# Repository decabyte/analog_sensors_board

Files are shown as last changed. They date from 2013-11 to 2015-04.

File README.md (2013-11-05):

Analog Sensors Shield
=====================

__Analog Sensors Shield__ is an Arduino Leonardo shield used to interface a robotic platform with analog sensors for internal environmental monitoring and platform managment.

The shild is using most of the analog inputs available on the Leonardo, reading data from 4 temperature sensors (LM35), 4 voltage divider for battery monitoring and a small humidity sensor (HIH-4030). 

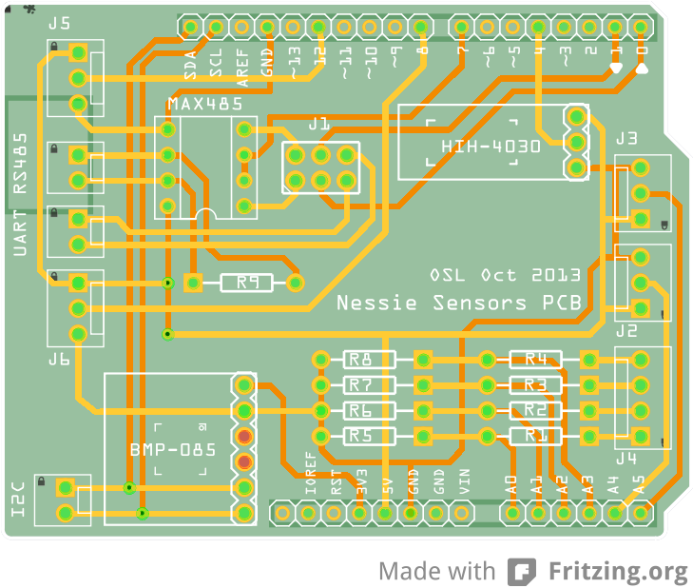
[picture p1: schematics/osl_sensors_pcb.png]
layout_pcb


In addition to the analog sensors the shield is using a BMP085 barometric pressure sensor interfaced with the I2C bus to provide extra temperature reading and platform monitoring. The BMP085 is powered by the Arduino itself using the 3.3V pin. To further expand the shield capabilities a MAX485 is included to provide an optional RS485 interface (using the J1 header one can select between UART or RS485 connectivity). The serial interfacing is achived using the Arduino hardware serial (pin 0 and 1) while the communication with the host is achieved using the 32U4 USB connection (using the CDC virtual serial profile as supported by Arduino Leonardo).

### Components

* 4 x LM35 analog temp sensor
* 4 x 24kOhm resistors (1%)
* 4 x 2.2kOhm resistors (1%)
* 1 x 150Ohm resistor (1%)
* 1 x BMP085 Breakout
* 1 x HIH-4030 Breakout

For a more detailed list look at [the bill of materials](extra/osl_sensors_bom.md) (or [html version](extra/osl_sensors_bom.html)) in the [extra](extra) subdir.

### Software

An example client python script is included in the [scripts](scripts) subdir, demostrating the use of the shield over the virtual serial connection (handling reconnects and catching exceptions). Being a an USB virtual serial connection means that the virtual interface is managed (using latest Linux distro) by `udev` subsystem and it will be attatched to the first available `/dev/ttyACMx` character device. To avoid this and to have a working symlink across reconnections customize the [rules](extra/99-local.rules) file with your Arduino's VID and PID.

Keep in mind that some extra features are missing but feel free to add or suggest them. Just clone or fork the git repository if you want to kickstart a new project.

## References

* [Temperature Sensor Tutorial](http://learn.adafruit.com/tmp36-temperature-sensor) 
* [HIH-4030 Humidity Sensor](https://www.sparkfun.com/products/9569)
* [HIH-4030 Tutorial](http://bildr.org/2012/11/hih4030-arduino/)
* [HIH-4030 Interpolation](http://forum.arduino.cc/index.php/topic,19961.0.html)
* [BMP085 Barometric Pressure Sensor](https://www.sparkfun.com/products/11282)
* [BMP085 Tutorial](https://www.sparkfun.com/tutorials/253)

## LICENSE - "MIT License"

Copyright (c) 2013-2014 Valerio De Carolis, http://decabyte.it

Permission is hereby granted, free of charge, to any person
obtaining a copy of this software and associated documentation
files (the "Software"), to deal in the Software without
restriction, including without limitation the rights to use,
copy, modify, merge, publish, distribute, sublicense, and/or sell
copies of the Software, and to permit persons to whom the
Software is furnished to do so, subject to the following
conditions:

The above copyright notice and this permission notice shall be
included in all copies or substantial portions of the Software.

THE SOFTWARE IS PROVIDED "AS IS", WITHOUT WARRANTY OF ANY KIND,
EXPRESS OR IMPLIED, INCLUDING BUT NOT LIMITED TO THE WARRANTIES
OF MERCHANTABILITY, FITNESS FOR A PARTICULAR PURPOSE AND
NONINFRINGEMENT. IN NO EVENT SHALL THE AUTHORS OR COPYRIGHT
HOLDERS BE LIABLE FOR ANY CLAIM, DAMAGES OR OTHER LIABILITY,
WHETHER IN AN ACTION OF CONTRACT, TORT OR OTHERWISE, ARISING
FROM, OUT OF OR IN CONNECTION WITH THE SOFTWARE OR THE USE OR
OTHER DEALINGS IN THE SOFTWARE.

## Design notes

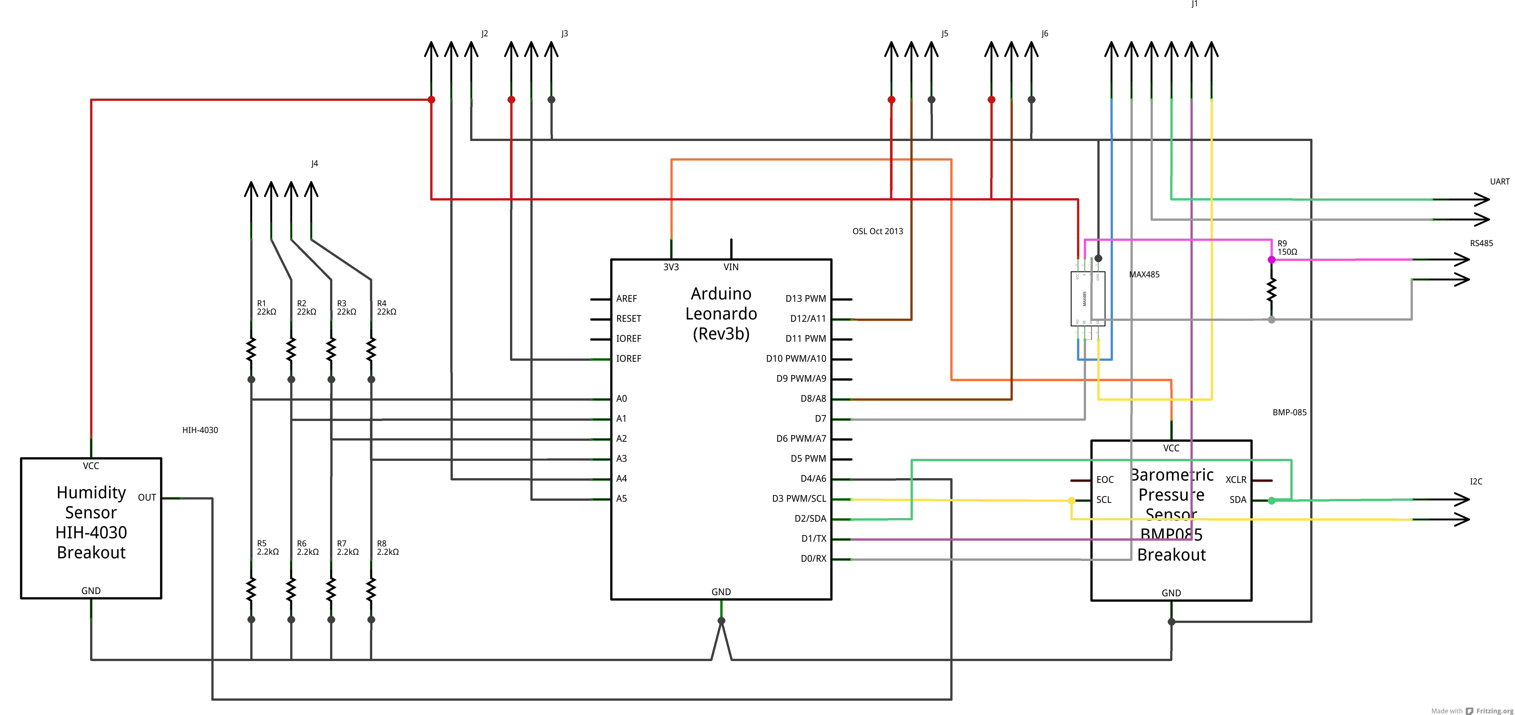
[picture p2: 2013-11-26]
schematics/osl_sensors_schem.png

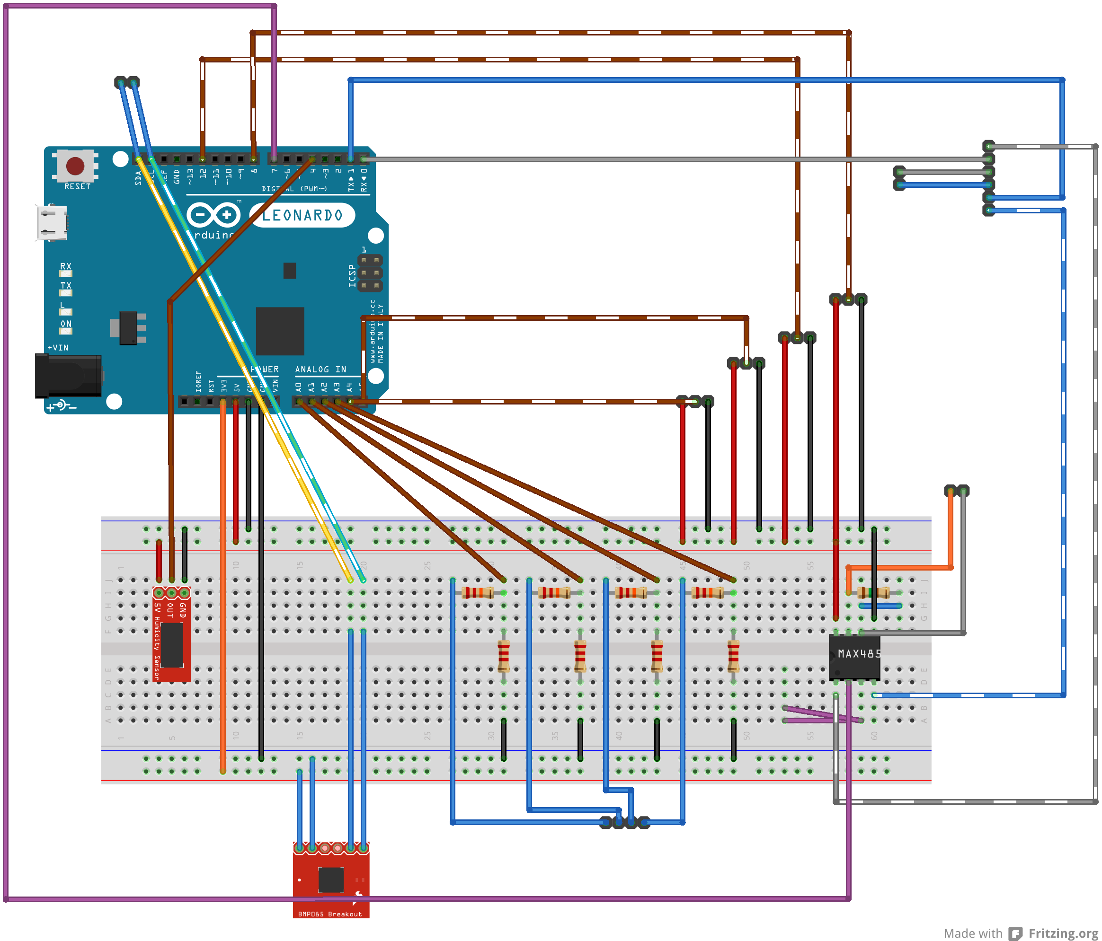
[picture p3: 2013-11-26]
schematics/osl_sensors_bb.png

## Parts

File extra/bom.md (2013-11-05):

Bill of Materials: osl\_sensors.fzz
===================================

Assembly List
-------------

Label          | Part Type                                      | Properties
---------------|------------------------------------------------|-----------------------------------------------------------------------------------------------------
BMP-085        | Barometric Pressure Sensor - BMP085 Breakout   | 
HIH-4030       | Humidity Sensor - HIH-4030 Breakout            | 
I2C            | Generic molex header - 2 pins                  | package THT; hole size 1.0mm,0.508mm; row single; form molex; pins 2; pin spacing 0.1in (2.54mm)
J1             | Generic double row male header - 6 pins        | package THT; hole size 1.0mm,0.508mm; row double; form ♂ (male); pins 6; pin spacing 0.1in (2.54mm)
J2             | Generic molex header - 3 pins                  | package THT; hole size 1.0mm,0.508mm; row single; form molex; pins 3; pin spacing 0.1in (2.54mm)
J3             | Generic molex header - 3 pins                  | package THT; hole size 1.0mm,0.508mm; row single; form molex; pins 3; pin spacing 0.1in (2.54mm)
J4             | Generic molex header - 4 pins                  | package THT; hole size 1.0mm,0.508mm; row single; form molex; pins 4; pin spacing 0.1in (2.54mm)
J5             | Generic molex header - 3 pins                  | package THT; hole size 1.0mm,0.508mm; row single; form molex; pins 3; pin spacing 0.1in (2.54mm)
J6             | Generic molex header - 3 pins                  | package THT; hole size 1.0mm,0.508mm; row single; form molex; pins 3; pin spacing 0.1in (2.54mm)
MAX485         | MAX485                                         | package dil08; variant dil
OSL Oct 2013   | Arduino Leonardo (Rev3b)                       | type Arduino Leonardo (Rev3)
R1             | 22k Ω Resistor                                 | package THT; tolerance ±1%; bands 4; resistance 22kΩ; pin spacing 400 mil
R2             | 22k Ω Resistor                                 | package THT; tolerance ±1%; bands 4; resistance 22kΩ; pin spacing 400 mil
R3             | 22k Ω Resistor                                 | package THT; tolerance ±1%; bands 4; resistance 22kΩ; pin spacing 400 mil
R4             | 22k Ω Resistor                                 | package THT; tolerance ±1%; bands 4; resistance 22kΩ; pin spacing 400 mil
R5             | 2.2k Ω Resistor                                | package THT; tolerance ±1%; bands 4; resistance 2.2kΩ; pin spacing 400 mil
R6             | 2.2k Ω Resistor                                | package THT; tolerance ±1%; bands 4; resistance 2.2kΩ; pin spacing 400 mil
R7             | 2.2k Ω Resistor                                | package THT; tolerance ±1%; bands 4; resistance 2.2kΩ; pin spacing 400 mil
R8             | 2.2k Ω Resistor                                | package THT; tolerance ±1%; bands 4; resistance 2.2kΩ; pin spacing 400 mil
R9             | 150 Ω Resistor                                 | package THT; tolerance ±1%; bands 4; resistance 150Ω; pin spacing 400 mil
RS485          | Generic molex header - 2 pins                  | package THT; hole size 1.0mm,0.508mm; row single; form molex; pins 2; pin spacing 0.1in (2.54mm)
UART           | Generic molex header - 2 pins                  | package THT; hole size 1.0mm,0.508mm; row single; form molex; pins 2; pin spacing 0.1in (2.54mm)

Shopping List
-------------

Amount   | Part Type                                      | Properties
---------|------------------------------------------------|-----------------------------------------------------------------------------------------------------
1        | Barometric Pressure Sensor - BMP085 Breakout   | 
1        | Humidity Sensor - HIH-4030 Breakout            | 
3        | Generic molex header - 2 pins                  | package THT; hole size 1.0mm,0.508mm; row single; form molex; pins 2; pin spacing 0.1in (2.54mm)
1        | Generic double row male header - 6 pins        | package THT; hole size 1.0mm,0.508mm; row double; form ♂ (male); pins 6; pin spacing 0.1in (2.54mm)
4        | Generic molex header - 3 pins                  | package THT; hole size 1.0mm,0.508mm; row single; form molex; pins 3; pin spacing 0.1in (2.54mm)
1        | Generic molex header - 4 pins                  | package THT; hole size 1.0mm,0.508mm; row single; form molex; pins 4; pin spacing 0.1in (2.54mm)
1        | MAX485                                         | package dil08; variant dil
1        | Arduino Leonardo (Rev3b)                       | type Arduino Leonardo (Rev3)
4        | 22k Ω Resistor                                 | package THT; tolerance ±1%; bands 4; resistance 22kΩ; pin spacing 400 mil
4        | 2.2k Ω Resistor                                | package THT; tolerance ±1%; bands 4; resistance 2.2kΩ; pin spacing 400 mil
1        | 150 Ω Resistor                                 | package THT; tolerance ±1%; bands 4; resistance 150Ω; pin spacing 400 mil

Exported with Fritzing 0.8.3- http://fritzing.org

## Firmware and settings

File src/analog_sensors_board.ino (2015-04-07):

/*
    analog_sensors_board.ino

    Connect LM35 temperature sensors to J2, J3, J5 and J6 and battery lanes to J4.
    This program will read analog values, apply data conversion and send back
    detected levels using the serial connection on the Arduino Leonardo board.

    Copyright (c) 2012-2013 Valerio De Carolis, http://decabyte.it

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
    THE SOFTWARE IS PROVIDED "AS IS", WITHOUT WARRANTY OF ANY KIND, EXPRESS OR
    IMPLIED, INCLUDING BUT NOT LIMITED TO THE WARRANTIES OF MERCHANTABILITY,
    FITNESS FOR A PARTICULAR PURPOSE AND NONINFRINGEMENT. IN NO EVENT SHALL THE
    AUTHORS OR COPYRIGHT HOLDERS BE LIABLE FOR ANY CLAIM, DAMAGES OR OTHER
    LIABILITY, WHETHER IN AN ACTION OF CONTRACT, TORT OR OTHERWISE, ARISING FROM,
    OUT OF OR IN CONNECTION WITH THE SOFTWARE OR THE USE OR OTHER DEALINGS IN THE
    SOFTWARE.
*/

// ** LM35 Analog Temperature Sensor
//  [1]: http://learn.adafruit.com/tmp36-temperature-sensor
//
// ** HIH-4043 Humidity Sensor
//  [2]: https://www.sparkfun.com/products/9569
//  [3]: http://bildr.org/2012/11/hih4030-arduino/
//  [4]: http://forum.arduino.cc/index.php/topic,19961.0.html
//
// ** BMP085 Barometric Pressure Sensor
//  [5]: https://www.sparkfun.com/products/11282
//  [6]: https://www.sparkfun.com/tutorials/253
//
//  [7]: http://linux.die.net/man/8/picocom
//  [8]: http://forum.arduino.cc/index.php?topic=128717.0
//  [9]: http://www.nongnu.org/avr-libc/user-manual/group__avr__watchdog.html

#include <avr/wdt.h>
#include <Wire.h>

#define DELAY_SETUP 250         // setup flashing delay
#define DELAY_LEDS 500          // led blink rate
#define DELAY_SLOW 5000         // slow acquisition loop
#define DELAY_FAST 250          // fast acquisition loop

#define INIT_COUNT 10           // initial loop count (reset protection)    

// Nessie LEDs and Water Sensors
#define LED_GREEN 6
#define LED_YELLOW 5
#define LED_RED 7
#define SW_MOTOR 9
#define WATER_FWD 10
#define WATER_AFT 11

#define BAT_LOW 26.5f
#define TH_MOTOR_HIGH 1
#define TH_MOTOR_LOW -100
#define TH_WATER 10


// Reference voltages (fine tuned):
//  measured using AREF when the shield is in place and 
//  the Arduino is powered by external power with vehicle
#define ADC_INTERNAL_V  0.002483f   // manual calibration (was 0.002502f)
#define ADC_INTERNAL_MV 2.483f      // manual calibration (was 2.502f)
#define ADC_DEFAULT_V 0.004887f     // uncalibrated
#define ADC_DEFAULT_MV 4.887f       // uncalibrated

// select the ADC reference to use for calculations
#define ADC_V ADC_DEFAULT_V
#define ADC_MV ADC_DEFAULT_MV

#define LED_PIN 13

#define BAT_R1 24000.0f         // R1 (ohm)
#define BAT_R2 2200.0f          // R2 (ohm)

#define LM35_MVC 10.0f          // mV/C
#define ACS715_MVA 133.0f       // mv/A
#define ACS714_MVA 185.0f       // mv/A

#define BMP085_ADDRESS 0x77     // I2C address
#define BMP085_OSS 0            // Oversampling Setting
#define BMP_MAX 1000            // Loop protection (number of loops)

// Voltage Divider (for battery levels)
const float BAT_RK = (BAT_R1 + BAT_R2) / BAT_R2;

// Allegro ACS715 0A to 30A     (using 2.56V ADC ref)
//const float ACS715_CONV = ADC_INTERNAL_MV / ACS715_MVA;         // Amps per ADC level
//const int ACS715_OFFSET = 202;                                  // ADC level (0.5 Vin @ 2.52 Vref ~= 202.2)

// Allegro ACS715 0A to 30A     (using 5.00V ADC ref)
const float ACS715_CONV = ADC_DEFAULT_MV / ACS715_MVA;          // Amps per ADC level
const int ACS715_OFFSET = 103;                                  // ADC level (0.5 Vin @ 5 Vref = 102.6)

// Allegro ACS714 current sensor
//const int ACS_ZERO = (int) 2500 / ADC_INTERNAL_MV;            // ADC reading for 2.5V (~ 1007)
//const float ACS714_CONV = ADC_INTERNAL_MV / ACS714_MVA;       // Amps per ADC level


// adc readings
int raw_bat0, raw_bat1, raw_bat2, raw_bat3;
int raw_tm0, raw_tm1, raw_tm2, raw_tm3;
int raw_hih;

// output values
float bat0, bat1, bat2, bat3;
float tm0, tm1, tm2, tm3;
float hih, hm, hb;


// BMP085 barometric pressure sensor
long raw_ut, raw_up;                    // BMP085 raw readings
short temperature;                      // local temperature
long pressure;                          // local pressure

// BMP085 loop control
short bmp_cnt;
byte bmp_dirty;
 
// BMP085 calibration values
int ac1, ac2, ac3;
unsigned int ac4, ac5, ac6;
int b1, b2, mb, mc, md; 

// b5 is calculated in bmp085GetTemperature(...), this variable is also used in
// bmp085GetPressure(...) so bmp085GetTemperature(...) must be called before
// bmp085GetPressure(...) to work correctly.
long b5;


// Allegro ACS714/715 current sensor 
//   * ACS714 output is 2.5V for 0A up to 4.5V at +5A and down to 0.5V at -5A
//   * ACS715 output is 0.5V for 0A up to 5V at 30A
int raw_acs0;
float acs0;


// time & timestamps
int delay_acs = 250;
unsigned long time_env;
unsigned long time_acs;
unsigned long time_leds;
unsigned long delta;

// default inputs
int status_water_fwd = 0;
int status_water_aft = 0;
int status_sw_motor = 0;

boolean water_detected = false;
boolean motors_enabled = false;

boolean status_led_green = false;
boolean status_led_yellow = false;
boolean status_led_red = false;


// the setup routine runs once when you press reset
void setup() {
    // disable watchdog
    wdt_disable();                  // used [8] as suggestion

    // not ready
    pinMode(LED_PIN, OUTPUT);
    digitalWrite(LED_PIN, LOW); 

    // LEDs and INPUTs init
    pinMode(LED_GREEN, OUTPUT); 
    pinMode(LED_YELLOW, OUTPUT); 
    pinMode(LED_RED, OUTPUT); 
    pinMode(SW_MOTOR, INPUT_PULLUP); 
    pinMode(WATER_FWD, INPUT); 
    pinMode(WATER_AFT, INPUT); 

    digitalWrite(LED_GREEN, LOW); 
    digitalWrite(LED_YELLOW, LOW); 
    digitalWrite(LED_RED, LOW); 

    // flash the on-board led while waiting for connection
    // while(!Serial) {
    //     digitalWrite(LED_PIN, HIGH);
    //     delay(DELAY_SETUP);
    //     digitalWrite(LED_PIN, LOW);
    //     delay(DELAY_SETUP);
    // }

    // switch to precise reference (2.56V)
    //analogReference(INTERNAL);

    // switch to default reference (5V on Arduino Uno/Leonardo)
    analogReference(DEFAULT);

    // Arduino Leonardo has some difficulties entering in bootloarder upload mode
    // if it is sending data to serial in loop() preventing firmware update without
    // triggering the manual reset using the push-button.
    //
    // A 5-sec initial delay is then inserted below to provide sufficent time after
    // a software-triggered reset to upload a new firmware using serial bootloader

    // reset protection delay (DO NOT REMOVE)
    for(int i=0; i < INIT_COUNT; i++) {
        // initial LEDs flashing
        digitalWrite(LED_GREEN, HIGH); 
        digitalWrite(LED_YELLOW, HIGH); 
        digitalWrite(LED_RED, HIGH);

        delay(1000);

        // reset LEDs
        digitalWrite(LED_GREEN, LOW); 
        digitalWrite(LED_YELLOW, LOW); 
        digitalWrite(LED_RED, LOW);                  
    }

    // enable watchdog
    wdt_enable(WDTO_8S);


    // bmp085 init
    Wire.begin();
    bmp085Calibration();            // read data from BMP085 registers
    report_bmp_calibration();       // send calibration data for reference

    // ready to go
    digitalWrite(LED_PIN, HIGH);
}


// the loop routine runs over and over again forever
void loop() {

    // serial control
    if(Serial.available() > 0) {
        char ser = (char) Serial.read();

        switch(ser) {
            case 'S':
                delay_acs = 1000;
                break;
            case 'N':
                delay_acs = 500;
                break;
            case 'F':
                delay_acs = 250;
                break;
            case 'R':
                wdt_disable();
                wdt_enable(WDTO_250MS);
                delay(1000);
                break;
            default:
                Serial.print("$SER,");
                Serial.println(ser);
        }
    }


    // water leak detectors
    //  latched dection after a thrsold
    if(!water_detected) {
        if(digitalRead(WATER_FWD) == LOW) {
            status_water_fwd += 1;
        }

        if(digitalRead(WATER_AFT) == LOW) {
            status_water_aft += 1;
        }

        if(status_water_fwd > TH_WATER || status_water_aft > TH_WATER) {
            water_detected = true;

            // send priority alert
            Serial.print("$WATER,");
            Serial.print(water_detected, DEC);
            Serial.print(",");
            Serial.print(status_water_fwd, DEC);
            Serial.print(",");
            Serial.println(status_water_aft, DEC);
        }
    }


    // sw_motor magnetic switch (hall-sensor)
    //      high:   magnetic key removed
    //      low:    magnetic key detected
    if(digitalRead(SW_MOTOR) == HIGH) {
        status_sw_motor += 1;
    } else {
        status_sw_motor -= 1;
    }

    // sw_motor hysteresis cycle
    if(status_sw_motor > TH_MOTOR_HIGH) {

        if(motors_enabled) {
            // send priority alert
            Serial.print("$MOTOR,");
            Serial.println(!motors_enabled, DEC);
        }

        motors_enabled = false;
        status_sw_motor = 0;
    }

    if(status_sw_motor < TH_MOTOR_LOW) {
        motors_enabled = true;
        status_sw_motor = 0;
    }


    // led indicator loop
    delta = millis() - time_leds;

    if(delta >= DELAY_LEDS) {

        // if(status_sw_motor == LOW) {
        //     status_led_green = true;
        // } else {
        //     status_led_green = !status_led_green;
        // }

        if(motors_enabled) {
            status_led_green = true;
        } else {
            status_led_green = !status_led_green;
        }

        // if(status_water_fwd == HIGH && status_water_aft == HIGH) {
        //     status_led_red = true;    
        // } else {
        //     status_led_red = !status_led_red;
        // }

        if(water_detected) {
            status_led_red = !status_led_red;    
        } else {
            status_led_red = true;
        }

        if( bat0 > BAT_LOW ) {
            status_led_yellow = true; 
        } else {
            status_led_yellow = !status_led_yellow; 
        }

        // led indications
        digitalWrite(LED_GREEN, status_led_green);
        digitalWrite(LED_YELLOW, status_led_yellow);
        digitalWrite(LED_RED, status_led_red);

        // update timestamp
        time_leds = millis();
    }


    // current sensor loop
    delta = millis() - time_acs;

    if(delta >= delay_acs) {
        // start acquisition (with double readings to avoid interferences [1])
        digitalWrite(LED_PIN, HIGH);

        // current sensor
        raw_acs0 = analogRead(A11);     // J5 (pin 2)
        raw_acs0 = analogRead(A11);     // J5 (pin 2)

        // signal end of acquisition
        digitalWrite(LED_PIN, LOW);

        // calculate output is Amps
        acs0 = (float) (raw_acs0 - ACS715_OFFSET)  * ACS715_CONV;
        //acs0 = (float) (ACS_ZERO - raw_acs0) * ACS714_CONV;

        // send current report
        report_current();

        // update timestamp
        time_acs = millis();
    }


    // environmental sensors loop
    delta = millis() - time_env;

    // limit data rate
    if(delta >= DELAY_SLOW) {
        // analog inputs (battery)
        raw_bat0 = analogRead(A0);      // J4 (pin 1)
        raw_bat0 = analogRead(A0);      // J4 (pin 1)

        raw_bat1 = analogRead(A1);      // J4 (pin 2)
        raw_bat1 = analogRead(A1);      // J4 (pin 2)

        raw_bat2 = analogRead(A2);      // J4 (pin 3)
        raw_bat2 = analogRead(A2);      // J4 (pin 3)

        raw_bat3 = analogRead(A3);      // J4 (pin 4)
        raw_bat3 = analogRead(A3);      // J4 (pin 4)

        // voltage level conversion
        bat0 = BAT_RK * (float)raw_bat0 * ADC_V;
        bat1 = BAT_RK * (float)raw_bat1 * ADC_V;
        bat2 = BAT_RK * (float)raw_bat2 * ADC_V;
        bat3 = BAT_RK * (float)raw_bat3 * ADC_V;

        // send battery report
        report_battery();


        // analog inputs (temperature)
        raw_tm0 = analogRead(A4);       // J2 (pin 2)
        raw_tm0 = analogRead(A4);       // J2 (pin 2)

        raw_tm1 = analogRead(A5);       // J3 (pin 2)
        raw_tm1 = analogRead(A5);       // J3 (pin 2)
        
        raw_tm2 = analogRead(A8);       // J6 (pin 2)
        raw_tm2 = analogRead(A8);       // J6 (pin 2)

        //raw_tm3 = analogRead(A11);        // J5 (pin 2)
        //raw_tm3 = analogRead(A11);        // J5 (pin 2)

        // lm35 temperature conversion
        tm0 = (float(raw_tm0) * ADC_MV) / LM35_MVC;
        tm1 = (float(raw_tm1) * ADC_MV) / LM35_MVC;
        tm2 = (float(raw_tm2) * ADC_MV) / LM35_MVC;
        //tm3 = (float(raw_tm3) * ADC_MV) / LM35_MVC;

        // send temperature report
        report_temperature();


        // pressure sensor
        raw_ut = bmp085ReadUT();                        // raw_ut = 27898;
        temperature = bmp085GetTemperature(raw_ut);     // compensated temperature

        raw_up = bmp085ReadUP();                        // raw_up = 23843;
        pressure = bmp085GetPressure(raw_up);           // compesated pressure

        // send pressure report
        report_pressure();
        bmp_dirty = 0;                  // reset dirty bits

        
        // humidity sensor
        raw_hih = analogRead(A6);       // HIH-4030 (pin 2)
        raw_hih = analogRead(A6);       // HIH-4030 (pin 2)

        // // ADC 2.56V ref -- relative humidity with temperature correction (see hih_4030_fitting.m)
        // hm = (0.0002f * temperature) + 0.0763f;         // x-coeffient fitting
        // hb = (-0.0612f * temperature) - 24.4265f;       // b-term fitting
        // hih = hm * float(raw_hih) + hb;                 // ADC ref (2.56 V)

        // ADC 5.00V ref -- relative humidity with temperature correction (see hih_4030_fitting.m)
        hm = (0.00038f * temperature) + 0.14900f;       // x-coeffient fitting
        hb = (-0.06166f * temperature) -24.43629f;      // b-term fitting
        hih = hm * float(raw_hih) + hb;                 // ADC ref (5.0 V)

        // send humidity report
        report_humidity();


        // send indicators report
        report_indicators();

        
        // send timestamp
        Serial.print("$TIME,");
        Serial.println(time_env, DEC);

        // update timestamp
        time_env = millis();
    }


    // reset watchdog
    wdt_reset();
}


void report_indicators() {
    Serial.print("$WATER,");
    Serial.print(water_detected, DEC);
    Serial.print(",");
    Serial.print(status_water_fwd, DEC);
    Serial.print(",");
    Serial.println(status_water_aft, DEC);

    Serial.print("$MOTOR,");
    Serial.println(motors_enabled, DEC);

    Serial.print("$LED,");
    Serial.print(status_led_green, DEC);
    Serial.print(',');
    Serial.print(status_led_yellow, DEC);
    Serial.print(',');
    Serial.println(status_led_red, DEC);
}


void report_current() {
    Serial.print("$ACS,");
    Serial.print(acs0, 4);
    Serial.print(',');
    Serial.print(raw_acs0, DEC);
    Serial.print(',');
    Serial.println(millis(), DEC);
}

void report_battery() {
    Serial.print("$BAT,");
    Serial.print(bat0, 4);
    Serial.print(',');
    Serial.print(bat1, 4);
    Serial.print(',');
    Serial.print(bat2, 4);
    Serial.print(',');
    Serial.print(bat3, 4);
    Serial.print(',');
    Serial.print(raw_bat0, DEC);
    Serial.print(',');
    Serial.print(raw_bat1, DEC);
    Serial.print(',');
    Serial.print(raw_bat2, DEC);
    Serial.print(',');
    Serial.println(raw_bat3, DEC);
}

void report_temperature() {
    Serial.print("$TEMP,");
    Serial.print(tm0, 2);
    Serial.print(',');
    Serial.print(tm1, 2);
    Serial.print(',');
    Serial.print(tm2, 2);
    Serial.print(',');
    Serial.print(tm3, 2);
    Serial.print(',');
    Serial.print(raw_tm0, DEC);
    Serial.print(',');
    Serial.print(raw_tm1, DEC);
    Serial.print(',');
    Serial.print(raw_tm2, DEC);
    Serial.print(',');
    Serial.println(raw_tm3, DEC);
}

void report_pressure() {
    Serial.print("$BMP,");
    Serial.print(temperature, DEC);
    Serial.print(',');
    Serial.print(pressure, DEC);
    Serial.print(',');
    Serial.print(raw_ut, DEC);
    Serial.print(',');
    Serial.print(raw_up, DEC);
    Serial.print(',');
    Serial.println(bmp_dirty, DEC);
}

void report_humidity() {
    Serial.print("$HIH,");
    Serial.print(hih, 2);
    Serial.print(',');
    Serial.println(raw_hih, DEC);
}

void report_bmp_calibration() {
    Serial.print("$BMPCAL,");
    Serial.print(ac1, DEC);
    Serial.print(',');
    Serial.print(ac2, DEC);
    Serial.print(',');
    Serial.print(ac3, DEC);
    Serial.print(',');
    Serial.print(ac4, DEC);
    Serial.print(',');
    Serial.print(ac5, DEC);
    Serial.print(',');
    Serial.print(ac6, DEC);
    Serial.print(',');
    Serial.print(b1 , DEC);
    Serial.print(',');
    Serial.print(b2 , DEC);
    Serial.print(',');
    Serial.print(mb , DEC);
    Serial.print(',');
    Serial.print(mc , DEC);
    Serial.print(',');
    Serial.print(md , DEC);
    Serial.print(',');
    Serial.println(bmp_dirty, DEC);
}


// *** BMP085 functions *** 

// Stores all of the bmp085's calibration values into global variables
// Calibration values are required to calculate temp and pressure
// This function should be called at the beginning of the program
void bmp085Calibration() {
    ac1 = bmp085ReadInt(0xAA);
    ac2 = bmp085ReadInt(0xAC);
    ac3 = bmp085ReadInt(0xAE);
    ac4 = bmp085ReadInt(0xB0);
    ac5 = bmp085ReadInt(0xB2);
    ac6 = bmp085ReadInt(0xB4);
    b1 = bmp085ReadInt(0xB6);
    b2 = bmp085ReadInt(0xB8);
    mb = bmp085ReadInt(0xBA);
    mc = bmp085ReadInt(0xBC);
    md = bmp085ReadInt(0xBE);

    // datasheet values (debug only)
    // ac1 = 408;
    // ac2 = -72;
    // ac3 = -14383;
    // ac4 = 32741;
    // ac5 = 32757;
    // ac6 = 23153;
    // b1 = 6190;
    // b2 = 4;
    // mb = -32768;
    // mc = -8711;
    // md = 2868;
}

// Calculate temperature given ut.
//
// Value returned will be in units of 0.1 deg C
short bmp085GetTemperature(unsigned int ut) {
  long x1, x2;
  
  x1 = ( ((long)ut - (long)ac6) * (long)ac5 ) >> 15;
  x2 = ((long)mc << 11)/(x1 + md);
  b5 = x1 + x2;

  return ((b5 + 8) >> 4);  
}

// Calculate pressure given up - calibration values must be known
// b5 is also required so bmp085GetTemperature(...) must be called first.
//
// Value returned will be pressure in units of Pa.
long bmp085GetPressure(unsigned long up) {
  long x1, x2, x3, b3, b6, p;
  unsigned long b4, b7;
  
  b6 = b5 - 4000;
  // Calculate B3
  x1 = (b2 * (b6 * b6) >> 12) >> 11;
  x2 = (ac2 * b6) >> 11;
  x3 = x1 + x2;
  b3 = (((((long)ac1)*4 + x3) << BMP085_OSS) + 2) >> 2;
  
  // Calculate B4
  x1 = (ac3 * b6)>>13;
  x2 = (b1 * ((b6 * b6) >> 12)) >> 16;
  x3 = ((x1 + x2) + 2) >> 2;
  b4 = (ac4 * (unsigned long)(x3 + 32768)) >> 15;
  
  b7 = ((unsigned long)(up - b3) * (50000 >> BMP085_OSS));

  if (b7 < 0x80000000)
    p = (b7<<1)/b4;
  else
    p = (b7/b4) << 1;
    
  x1 = (p >> 8) * (p >> 8);
  x1 = (x1 * 3038) >> 16;
  x2 = (-7357 * p) >> 16;
  p += (x1 + x2 + 3791) >> 4;
  
  return p;
}

// // Read 1 byte from the BMP085 at 'address'
// char bmp085Read(unsigned char address)
// {
//   unsigned char data;
//  
//   Wire.beginTransmission(BMP085_ADDRESS);
//   Wire.write(address);
//   Wire.endTransmission();
//  
//   Wire.requestFrom(BMP085_ADDRESS, 1);
//   while(!Wire.available()) {
//
//   }
//
//   data = Wire.read();
//   return data;
// }

// Read 2 bytes from the BMP085
//
// First byte will be from 'address'
// Second byte will be from 'address'+1
int bmp085ReadInt(unsigned char address) {
  unsigned char msb, lsb;
  
  Wire.beginTransmission(BMP085_ADDRESS);
  Wire.write(address);
  Wire.endTransmission();
  
  Wire.requestFrom(BMP085_ADDRESS, 2);

  // loop check
  bmp_cnt = 0;

  // wait for data to become available
  while(Wire.available() < 2) {
    bmp_cnt += 1;

    if(bmp_cnt > BMP_MAX) {
        bmp_dirty = 1;
        return -1;
    }
  }
 
  msb = Wire.read();
  lsb = Wire.read();
  
  return (int) msb<<8 | lsb;
}

// Read the uncompensated temperature value
unsigned int bmp085ReadUT() {
  unsigned int ut;
  
  // Write 0x2E into Register 0xF4
  // This requests a temperature reading
  Wire.beginTransmission(BMP085_ADDRESS);
  Wire.write(0xF4);
  Wire.write(0x2E);
  Wire.endTransmission();
  
  // Wait at least 4.5ms
  delay(5);
  
  // Read two bytes from registers 0xF6 and 0xF7
  ut = bmp085ReadInt(0xF6);
  return ut;
}

// Read the uncompensated pressure value
unsigned long bmp085ReadUP() {
  unsigned char msb, lsb, xlsb;
  unsigned long up = 0;
  
  // Write 0x34+(BMP085_OSS << 6) into register 0xF4
  // Request a pressure reading w/ oversampling setting
  Wire.beginTransmission(BMP085_ADDRESS);
  Wire.write(0xF4);
  Wire.write(0x34 + (BMP085_OSS << 6));
  Wire.endTransmission();
  
  // Wait for conversion, delay time dependent on BMP085_OSS
  delay(2 + (3 << BMP085_OSS));
  
  // Read register 0xF6 (MSB), 0xF7 (LSB), and 0xF8 (XLSB)
  Wire.beginTransmission(BMP085_ADDRESS);
  Wire.write(0xF6);
  Wire.endTransmission();
  Wire.requestFrom(BMP085_ADDRESS, 3);
  
  // loop check
  bmp_cnt = 0;

  // wait for data to become available
  while(Wire.available() < 3) {
    bmp_cnt += 1;

    if(bmp_cnt > BMP_MAX) {
        bmp_dirty = 1;
        return -1;
    }
  }

  msb = Wire.read();
  lsb = Wire.read();
  xlsb = Wire.read();
  
  up = (((unsigned long) msb << 16) | ((unsigned long) lsb << 8) | (unsigned long) xlsb) >> (8 - BMP085_OSS);
  return up;
}

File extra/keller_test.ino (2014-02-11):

/**

@author thewknd
@date 7.2012

@copyright
This work is licensed under the Creative Commons Attribution-ShareAlike 3.0 Unported License. To view a copy of this license, visit http://creativecommons.org/licenses/by-sa/3.0/ or send a letter to Creative Commons, 444 Castro Street, Suite 900, Mountain View, California, 94041, USA.
*/

#include <kellerbus.h>
#include <Time.h>
#include <SoftwareSerial.h>

#define RTS_PIN 7
#define EXTRA 0

CKellerBus kbus((Stream*)&Serial1, 9600, RTS_PIN, 250);


time_t kbusTime;

void setup() {
  Serial.begin(115200);
  Serial1.begin(9600);
  while (!Serial) ;
}


void loop() {
  uint8_t mclass,group,myear,week,cfg_p,cfg_t,cnt_t,buffer,state;

  uint16_t pageAddress;
  uint16_t actPageAddress, startPageAddress, endPageAddress, timegap;
  uint8_t index = 0, overflow = 0, offset = 0, datatype, chan;
  float measure;
  char txt[4];
  uint32_t tmptime;

  Serial.println("\n-- KELLERBUS --");

  kbus.initDevice(250,&mclass,&group,&myear,&week,&buffer,&state);
  Serial.print("TYPE            : ");
  Serial.print(mclass,DEC);
  Serial.print(".");
  Serial.print(group,DEC);
  Serial.print("-");
  Serial.print(myear,DEC);
  Serial.print(".");
  Serial.println(week,DEC);
  Serial.print("BUFFER          : ");
  Serial.println(buffer,DEC);
  Serial.print("STATE           : ");
  Serial.println(state,BIN);
  Serial.print("SN              : ");
  Serial.println(kbus.getSerialnumber(),DEC);
  Serial.print("DEVICE ADDRESS  : ");
  kbus.writeDeviceAddress(0);
  Serial.println(kbus.getDeviceAddress(),DEC);
  Serial.print("BAT. CAPACITY   : ");
  Serial.println(kbus.readBatCapacity(),DEC);
  kbusTime = kbus.readDeviceTime(); 
  Serial.print("DEVICE TIME     : "); 
  Serial.print(day(kbusTime),DEC);
  Serial.print(".");
  Serial.print(month(kbusTime),DEC);
  Serial.print(".");
  Serial.print(year(kbusTime),DEC);
  Serial.print(" ");
  Serial.print(hour(kbusTime),DEC);
  Serial.print(":");
  Serial.print(minute(kbusTime),DEC);
  Serial.print(":");
  Serial.print(second(kbusTime),DEC);
  Serial.println(" (d:m:y h:m:s)");

  Serial.println("\n\r- Configuration -");
  kbus.readConfiguration(&cfg_p,&cfg_t,&cnt_t);
  Serial.print("CFG_P           : ");
  Serial.println(cfg_p,BIN);
  Serial.print("CFG_T           : ");
  Serial.println(cfg_t,BIN);
  Serial.print("CNT_T           : ");
  Serial.println(cnt_t,BIN);
  
  Serial.println("\n\r- Measurement -");
  Serial.print("CH0             : ");
  Serial.println(kbus.getCH0(),DEC);
  Serial.print("P1              : ");
  Serial.println(kbus.getP1(P_BAR),DEC);
  Serial.print("P2              : ");
  Serial.println(kbus.getP2(P_BAR),DEC);
  Serial.print("TOB1            : ");
  Serial.println(kbus.getTOB1(T_DEGC),DEC);
  Serial.print("TOB2            : ");
  Serial.println(kbus.getTOB2(T_DEGC),DEC);
  Serial.print("T               : ");
  Serial.println(kbus.getT(T_DEGC),DEC);
  
  Serial.println("\n\r- Gain/Offset -");
  Serial.println("Channel           Offset               Gain");  
  Serial.print("P1              : "); 
  Serial.print(kbus.readScalingValue(64),DEC); 
  Serial.print("        ");
  Serial.println(kbus.readScalingValue(65),DEC);
  Serial.print("P2              : "); 
  Serial.print(kbus.readScalingValue(66),DEC); 
  Serial.print("        ");
  Serial.println(kbus.readScalingValue(67),DEC);
  Serial.print("ANALOG          : "); 
  Serial.print(kbus.readScalingValue(68),DEC); 
  Serial.print("        ");
  Serial.println(kbus.readScalingValue(69),DEC);
  Serial.print("CH0             : "); 
  Serial.print(kbus.readScalingValue(70),DEC); 
  Serial.print("        ");
  Serial.println(kbus.readScalingValue(71),DEC);
  
  Serial.println("\n\r- Calibration data -");
  Serial.println("Channel           Min                  Max");  
  Serial.print("P1              : "); 
  Serial.print(kbus.pressureConversion(kbus.readScalingValue(80),P_BAR),DEC); 
  Serial.print("         ");
  Serial.println(kbus.pressureConversion(kbus.readScalingValue(81),P_BAR),DEC);
  Serial.print("P2              : "); 
  Serial.print(kbus.pressureConversion(kbus.readScalingValue(82),P_BAR),DEC); 
  Serial.print("         ");
  Serial.println(kbus.pressureConversion(kbus.readScalingValue(83),P_BAR),DEC);
  Serial.print("T               : "); 
  Serial.print(kbus.pressureConversion(kbus.readScalingValue(84),T_DEGC),DEC); 
  Serial.print("       ");
  Serial.println(kbus.pressureConversion(kbus.readScalingValue(85),T_DEGC),DEC);
  Serial.print("TOB1            : "); 
  Serial.print(kbus.pressureConversion(kbus.readScalingValue(86),T_DEGC),DEC); 
  Serial.print("       ");
  Serial.println(kbus.pressureConversion(kbus.readScalingValue(87),T_DEGC),DEC);
  Serial.print("TOB2            : "); 
  Serial.print(kbus.pressureConversion(kbus.readScalingValue(88),T_DEGC),DEC); 
  Serial.print("       ");
  Serial.println(kbus.pressureConversion(kbus.readScalingValue(89),T_DEGC),DEC);
  Serial.print("CH0             : "); 
  Serial.print(kbus.readScalingValue(90),DEC); 
  Serial.print("        ");
  Serial.println(kbus.readScalingValue(91),DEC);
  Serial.print("ANALOG          : "); 
  Serial.print(kbus.readScalingValue(94),DEC); 
  Serial.print("         ");
  Serial.println(kbus.readScalingValue(95),DEC);
  
  

  Serial.println("\n\r- Record cfg -");
  Serial.print("First page      : "); 
  Serial.println(kbus.readRecRomFirstPagePhysik(),DEC); 
  Serial.print("Last page       : "); 
  Serial.println(kbus.readRecRomLastPagePhysik(),DEC); 
  Serial.print("FUNC            : "); 
  Serial.println(kbus.readFUNC(),BIN); 
  Serial.print("CFG             : "); 
  Serial.println(kbus.readRECCFG(),BIN); 
  Serial.print("REC_CTRL        : "); 
  Serial.println(kbus.readRECCTRL(),BIN); 
  Serial.print("EE_CTRL         : "); 
  Serial.println(kbus.readEECTRL(),BIN); 
  Serial.print("Record starttime: "); 
  kbusTime = kbus.readRecordStartTime(); 
  Serial.print(day(kbusTime),DEC);
  Serial.print(".");
  Serial.print(month(kbusTime),DEC);
  Serial.print(".");
  Serial.print(year(kbusTime),DEC);
  Serial.print(" ");
  Serial.print(hour(kbusTime),DEC);
  Serial.print(":");
  Serial.print(minute(kbusTime),DEC);
  Serial.print(":");
  Serial.print(second(kbusTime),DEC);
  Serial.println(" (d:m:y h:m:s)");

  actPageAddress = kbus.readActualPageAddress();
  Serial.print("Actual page     : "); 
  Serial.println(actPageAddress,DEC); 


  // measurements
  do {
    Serial.println("\n\r- Measurement -");
    Serial.print("CH0             : ");
    Serial.println(kbus.getCH0(),DEC);
    Serial.print("P1              : ");
    Serial.println(kbus.getP1(P_BAR),DEC);
    Serial.print("P2              : ");
    Serial.println(kbus.getP2(P_BAR),DEC);
    Serial.print("TOB1            : ");
    Serial.println(kbus.getTOB1(T_DEGC),DEC);
    Serial.print("TOB2            : ");
    Serial.println(kbus.getTOB2(T_DEGC),DEC);
    Serial.print("T               : ");
    Serial.println(kbus.getT(T_DEGC),DEC);

    delay(1000);
  } while(1);
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

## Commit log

2013-11-15 updated reference voltages and watchdog timer
2013-11-25 initial acs714 current sensor support
2013-11-25 fixed trailing comma and coefficients names
    [analog_sensors_board.ino]
2013-11-25 updated schematics for SDA/SCL mismatch in fritzing library (ver 0.8.3b)
    [osl_sensors.fzz]
2013-11-26 updated firmware to use ACS715 current sensors, using two acquisition loops (fast and slow) for current and other sensors.
2013-11-26 updated schematics and source code indentation
    [osl_sensors.fzz]
2013-12-10 added initial delay for reset purposes
    [analog_sensors_board.ino]
2014-02-11 temporary implementation of LEDs indicators and water sensing
2014-02-11 updated indicator leds logic
2014-02-11 updated indicator leds logic + reporting
2014-02-11 updated LEDs indicator logic with dedicated loop and boolean logic
2014-02-12 improved level detections plus boolean flags for LEDs
2014-02-13 inserted initial delay to prevents hangs during new firmware uploads
    [analog_sensors_board.ino]
2014-02-13 updated motor alert condition
2014-02-14 updated safety condition for motor switch
2014-02-14 added internal pullup on motor switch
2015-04-07 added full range ADC conversion for ACS current sensor
2015-04-07 added more reset protection
    [analog_sensors_board.ino]
2015-04-07 fixed ACS715 offset calculation
    [analog_sensors_board.ino]
2015-04-07 unified the ADC reference used for calculations
2015-04-07 fixed humidity calculation with new ADC ref
    [analog_sensors_board.ino]
